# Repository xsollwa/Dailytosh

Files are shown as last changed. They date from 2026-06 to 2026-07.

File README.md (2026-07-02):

# DailyTosh
MacIntosh inspired **custom e-ink dashboard** featuring the hottest big-tech updates (+ the weather) and doubling as a business card holder!

[Click here for the demo video.](https://youtube.com/shorts/gpUzyWor4Is?si=RLWrw7KMKyLjlZAB)

**Photos:**




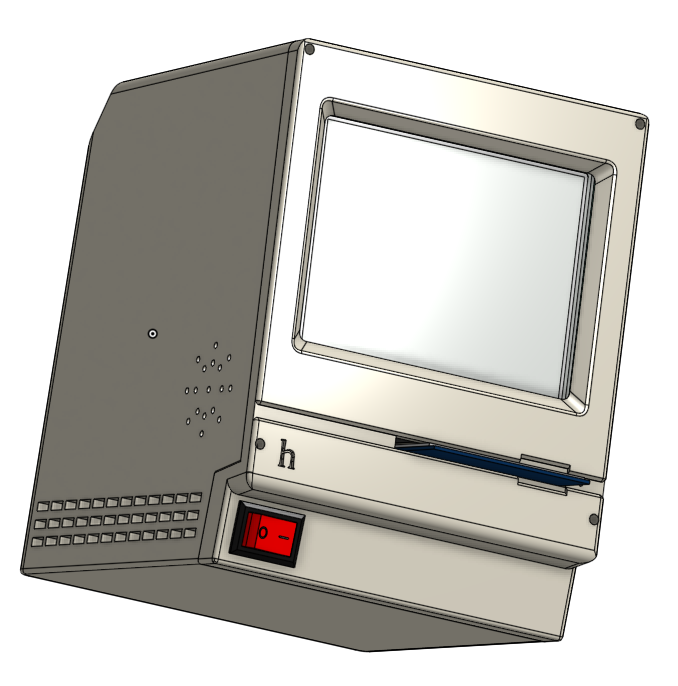
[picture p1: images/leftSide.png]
Side

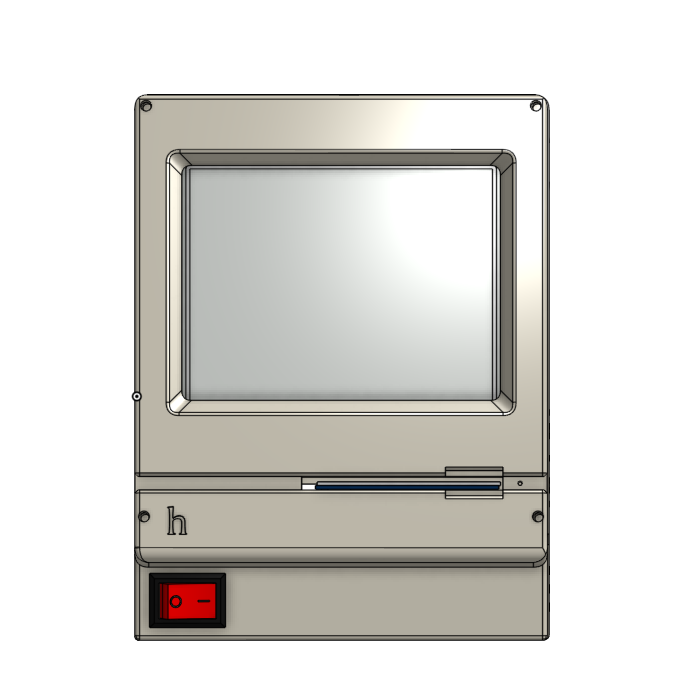
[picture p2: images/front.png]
Front

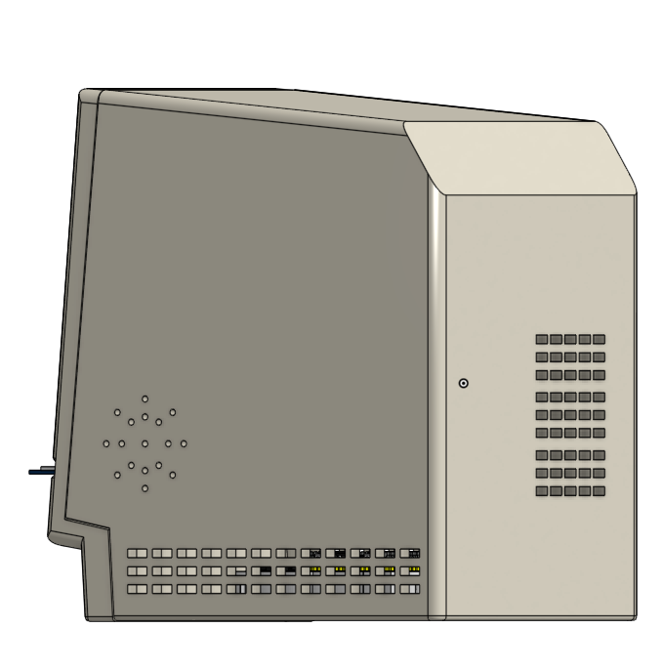
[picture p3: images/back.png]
Back

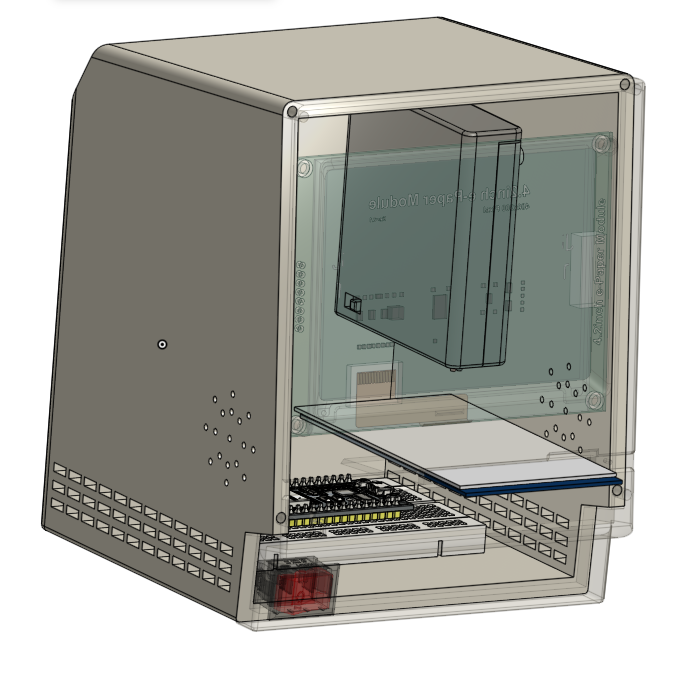
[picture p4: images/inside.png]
inside

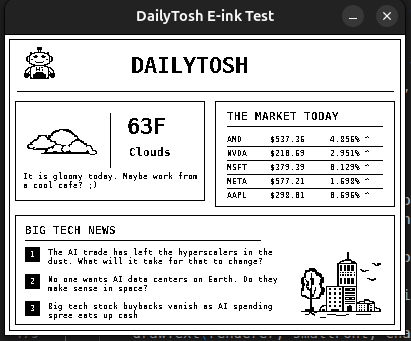
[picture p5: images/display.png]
display


## Why I made this project
Every morning, before heading out to school or work, I usually *check the weather, listen to WSJ Tech News Briefing and view market updates*. I realized a custon e-ink dashboard displaying all of this information would keep me informed more effotlessly! I was also interested in how E-Ink displays can fetch and display live information over Wi-Fi, and needed a better place to store my business cards.

*Built for Hack Club Outpost^^*

## Features
- Displays the most important big-tech news
- Shows major technology sector market changes
- Shares the weather of the day and suggests ideal workspace based on weather conditions 
    - Nice weather -> work outside
    - Rainy/snowy/windy weather -> work from home
    - Cloudy weather -> work at a coffee shop/library
- Uses an E-Ink display for less power consumption
- Doubles as a business card holder with its disk opening

## How It Works
DailyTosh is ESP32 based and uses a Waveshare E-Ink display

1. The ESP32 connects to Wi-Fi
2. It fetches data from OpenWeatherMap API (weather data) and Finnhub API (market and news data)
3. Data is processed and displayd with a dashboard layout
4. DailyTosh also includes a power switch!

### Wiring Diagram

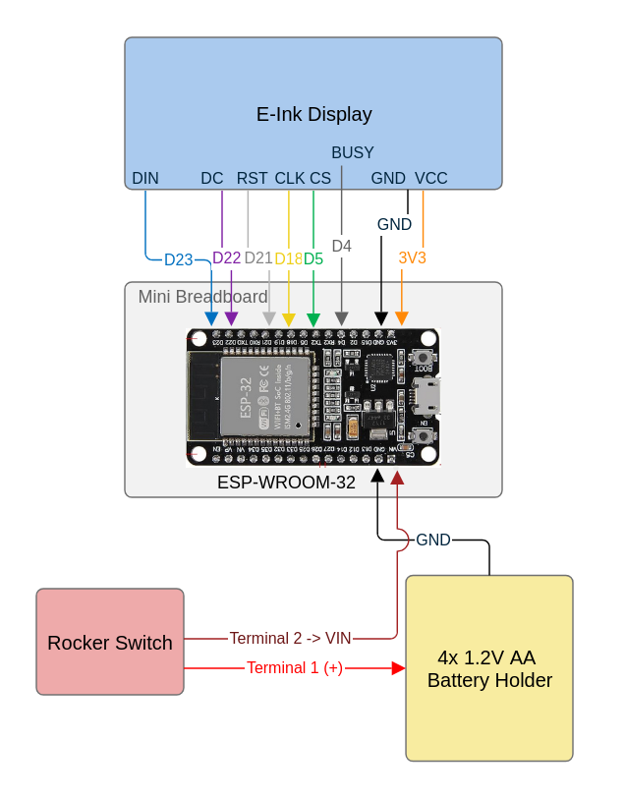
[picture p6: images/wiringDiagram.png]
Wiring Diagram


### Firmware

The ESP32 firmware *fetches weather, market and news data* from 2 APIs, processes the information and renders a custom dashboard on the E-Ink display.

**A custom filtering algorithm** scans over 100 big-tech keywords (for example " ai ", "amd", "semiconductor") to find the most relevant technology headlines on Finnhub. The firmware *refreshes every 24 hours* and was first developed as a **desktop C++ simulator** before being converted into ESP32 firmware in Arduino.

## Bill of Materials (BOM)

| Item | Purpose | Quantity | Cost | Link |
|---|---|---|---|---|
| Switch | Turning the power on/off | 1 | $0.00 (Owned) | [Link](https://a.co/d/0hRUtY8s) |
| M3 Bolts, Nuts, and Threaded Inserts | Mounting the components | 10 | $0.00 (Owned) | - |
| Cream PLA Filament | Printing the enclosure | 1 | $0.00 (Owned) | [Link](https://a.co/d/07ec5Kyy) |
| Micro USB Cable | Programming the ESP32 | 1 | $6.99 | [Link](https://a.co/d/0cJpSzp2) |
| Mini Breadboard and Jumper Wires | Connecting the circuit | 1 | $0.00 (Owned) | [Link](https://a.co/d/0ctxR1cS) |
| AA Batteries | Powering the circuit | 4 | $0.00 (Owned) | [Link](-) |
| 4 AA Battery Holder | Holding and connecting the batteries | 1 | $0.00 (Owned) | [Link](https://a.co/d/0bJuIjxS) |
| ESP-WROOM-32 | Processing and displaying information | 1 | $9.39 | [Link](https://a.co/d/0hTfNaHV) |
| 4.2" E-Ink Display (with matching cable) | Displaying information on the dashboard | 1 | $34.99 | [Link](https://www.waveshare.com/4.2inch-e-paper-module.htm) |

**Total Cost:** $51.37  
**Shipping:** $10.00  
**Taxes:** $1.84  

**Grand Total:** $63.21

## References
I used several resources for inspiration, learning and visualization purposes

### Tutorials
**ESP32 and Waveshare E-Ink Display Tutorial from YouTube:** Used to learn how to connect a Waveshare E-Ink display to an ESP32

https://youtu.be/El38zVmog14?si=65B1_IF447uCydue

### Design Inspiration
**The 20 Greatest Home Computers – The Guardian**: Reading through this article showed me a lot of cool famous computer designs

https://www.theguardian.com/games/2020/sep/07/the-20-greatest-home-computers-ranked

**Apple Macintosh (1984)**: The design and the name of DailyTosh is inspired by the original Macintosh computer

### CAD Models
These CAD models from GrabCAD were used in the Assembly for visualization purposes
- ESP-WROOM-32 model
- 4.2" Waveshare E-Ink Display
- Mini breadboard
- 4xAA Battery Holder

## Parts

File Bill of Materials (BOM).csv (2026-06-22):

Component | Purpose | Quantity | Total Price | Link | Distributor
Switch | Turning the power on/off | 1 | $0.00 | https://a.co/d/0hRUtY8s | N/A, I have it
M3 bolts, nuts and threaded inserts $0.00 - N/A, I have it | Mounting the components | 10 | $0.00 | N/A | N/A, I have it
Cream PLA | Printing the case | 1 | $0.00 | https://a.co/d/07ec5Kyy | N/A, I have it
Micro USB Cable | Programming the ESP32 | 1 | $6.99 | https://a.co/d/0cJpSzp2 | Amazon
Mini breadboard and jumping wires | Connecting the circuit | 1 | $0.00 | https://a.co/d/0ctxR1cS | N/A, I have it
AA batteries | Powering the circuit | 4 | $0.00 | N/A | N/A, I have it
4 AA Battery Holder | Holding the batteries | 1 | $0.00 | https://a.co/d/0bJuIjxS | N/A, I have it
ESP-WROOM-32 | Processing and displaying info | 1 | $9.39 | https://a.co/d/0hTfNaHV | Amazon
4.2inch E-Ink display w/ matching cable | Displaying information on the dashboard | 1 | $34.99 | https://www.waveshare.com/4.2inch-e-paper-module.htm | Waveshare
 | Tax: $1.84 | Shipping: $10.00
 | Total: $63.21

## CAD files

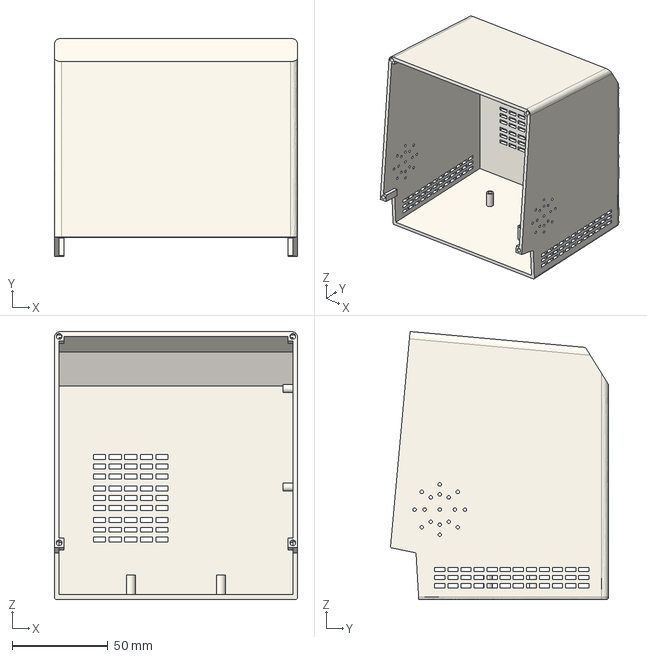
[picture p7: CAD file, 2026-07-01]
CAD/CaseFinal.step
127.0 x 113.9 x 139.9 mm

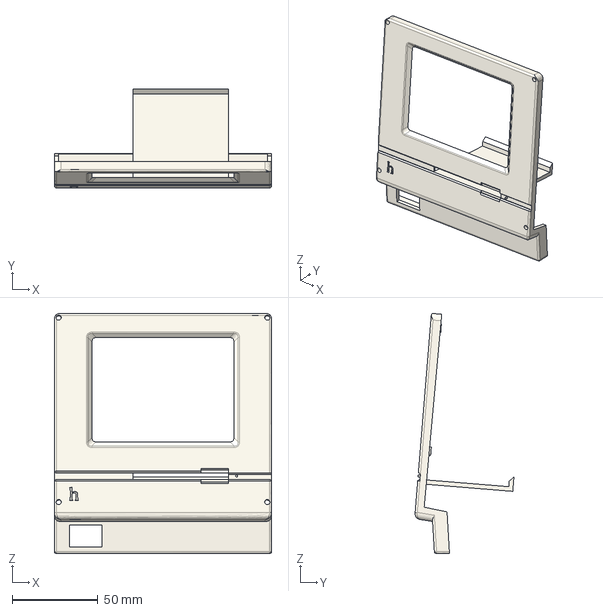
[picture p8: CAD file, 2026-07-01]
CAD/LidFinal.step
127.0 x 57.8 x 140.3 mm

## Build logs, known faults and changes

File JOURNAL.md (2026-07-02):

<!--
  This journal is auto generated by Stasis.
-->
# 7/1/2026 5 PM - Printing, sandpapering, assembling, demoing

_Time spent: 3.5h_

My printer printed the revised CAD model really badly, and after reprinting it a couple of more times, I decided to accept my fate and smooth out the case and the lid with sandpaper. After it looked smooth enough, I inserted the threaded inserts, redid some soldering, assembled my project, and recorded the demo! Unfortunately I forgot to document how horrible my print looked before sanding but here is a photo of my final project!



# 6/30/2026 6 PM - Fixing the CAD model

_Time spent: 1.5h_

To test out my 3D model, I printed out a prototype with the worst PLA I have on the fastest printing speed. As I tried placing my electrical components into the casing, I realized that my CAD had quite a few mistakes (e.g. cutouts that were too small, shell that was too thick and the whole model was pretty big for no reason). I also figured that I do not really need a breadboard. With that, I went back on OnShape, fixed all of those errors and sent the revised model to the printer. I also updated the repo with updated CAD models.




# 6/30/2026 1 AM - Building the Full Circuit

_Time spent: 1.5h_

After I got the software to work properly, I started assembling the full circuit by soldering the battery holder with the switch, and connecting them with the ESP32. At first, my ESP32 showed no signs of life. After checking the wiring and testing the batteries with a multimeter, I found no obvious connection issues. As a final test, I replaced the 3 rechargeable batteries with a fresh set of non-rechargeable ones. Fortunately, the circuit powered on!! The rechargeable batteries were most likely providing slightly less voltage than the ESP32 needed through the VIN pin :D

(I will have better wire management once my tape arrives....)



# 6/29/2026 9 PM - Testing Hardware and Fixing Software

_Time spent: 4h_

The hardware components of this project have finally arrived, and I proceeded with testing the ESP32 and then wired in the E-ink screen. After trying to run my firmware, it did not compile and I realized that it has a ton of bugs, since it was not tested before on an ESP32. I started by copy and pasting my old code and fixing it step by step in a new Arduino sketch. This made debugging less overwhelming. I spent lots of time adjusting the layout, re-converting my art to 0s and 1s and other such design things before utilizing the APIs. After I was satisfied with the layout, I plugged in the WiFi+API functionality and voila! The software works! 




# 6/22/2026 5 AM - All things Firmware and Finish

_Time spent: 0.75h_

To finish up the design for this project, I converted my bill of materials to a csv format and added it to the repository along with the firmware and additional assets. 

I also thought that I should journal my firmware development process here!

Since I did not have the ESP32 nor the E-Ink display yet, I first made a desktop c++ simulator that could fetch weather, market and news data from APIs and display everything in a "dashboard" view using a SDL2 simulation of a 400x300 pixel display. 

As I revised the layout, I added multiple stocks, pixel-art, weather based workspace recommendations and a custom filtering algorithm that scans 100+ tech related keywords to find relevant headlines. 

Once the simulator was working, I converted the code into esp32 compatible firmware by replacing the desktop networking, json and graphics libraries with the  stuff that can run on the microcontroller. 

Anyway, here is a screenshot of my simulated e-ink dashboard!

display

Also the first hour of my firmware  time was unfortunately not recorded in Hackatime because I initially wasn't working inside a project folder :__)



# 6/22/2026 2 AM - Pixel Art

_Time spent: 1.5h_

I used the Piskel platform to sketch out some pixel art for DailyTosh E-ink dashboard ui. I made a 32x32 mini robot, 64x64 clouds and a 64x64 city. This was my first time doing pixel art and I found it pretty fun.

 I also planned the overall dashboard layout for the display to neatly show the weather, market updates, and top 3 big tech headlines. 

New Piskel

New Piskel(1)

New Piskel(2)





# 6/20/2026 9 PM - README.md, Repo and Arduino IDE/Hackatime Setup

_Time spent: 2h_

I created and organized the GitHub repository for DailyTosh with all CAD files and project images. I also spent time writing and revising the README.md to include all of the required info and references. Since I recently started working on a new computer, I installed and configured Arduino IDE and connected Hackatime to track my firmware time down the line in this project.





# 6/20/2026 3 AM - Wiring Diagram and Tutorials

_Time spent: 2h_

First, I watched several YouTube tutorials and guides on how to connect a Waveshare E-Ink Display pins to an ESP32 board, since the Waveshare website did not explicitly say that my selected e-ink display can be used with ESP32 boards. 

After making sure that all of my components are compatible with each other, I made the wiring diagram for this project on SmartDraw. This diagram making platform was pretty painful to use (or maybe I just haven't figured out how to use it properly yet), so I hope to find a better one for my future projects.

Here is the wiring diagram:





# 6/20/2026 12 AM - Finished CAD Assembly

_Time spent: 1h_

Finished up the computer lid by adding mounting holes, the E-ink display and the switch. Assembled the final 3d model. 

I also made sample business cards to show how the business-card-holding slot is intended to look :)









Almost everything will be mounted using threaded inserts and screws, and the breadboard will be mounted using its sticky bottom or two-sided tape. I decided to use a breadboard instead of a pcb in this project because my circuit has only 4 components. I thought it would be more cost efficient than a pcb, especially because my soldering iron does not work :_)






# 6/19/2026 11 PM - CAD-ed the Case

_Time spent: 2h_

I designed the main old-computer looking case in OnShape. I also imported the electronic components that it holds (the batteries with the holder and the breadboard with ESP32) form GrabCAD and started my assembly.





I also revised my Bill of Materials to include threaded inserts for mounting and exclude the items that I already own (PLA and breadboard) to bring the material cost down.




# 6/19/2026 9 PM - CAD-ed the lid

_Time spent: 2h_

I designed the lid for the computer/display frame/electronics casing in OnShape. It is inspired by the Apple Macintosh computer. I also decided to make the opening for the disk drive into a business card holder to add another small feature (I have to many business cards laying on my desk)








# 6/19/2026 4 PM - Brainstorming and Design

_Time spent: 4h_

I want to make my own e-ink dashboard, so I started with brainstorming ideas on what it can display. I have been listening to Wall Street Journal tech minute everyday, so I ultimately decided to make an e-ink dashboard that would show big tech news, market changes and the weather.

I spent about an hour researching what APIs I can use for the information that I need. I will go with OpenWeatherMap API and Finnhub API, since they have free options and are "user friendly". 

I spent the next hour figuring out what my dashboard will look like. I wanted it to have a vintage look and be related to "big tech". I read this article called "The 20 greatest home computers ranked", and the 1984 Apple Macintosh became my design inspo. From there came the project name "Dailytosh"





For the last two hours, I searched for the most affordable options of the materials that I will need. An affordable e-ink display that is ESP32 compatible (for Wi-Fi purposes) was the hardest to find. I also made and entered my Bill of Materials on this website.




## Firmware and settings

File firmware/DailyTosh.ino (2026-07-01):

/*DailyTosh firmware!
 *This code connects the ESP32 to WiFi, 
 *fetches weather, stock and tech news, 
 *displays it on the e-ink screen, 
 *then puts the ESP32 into sleep until the next day
 *(translated to .ino syntax from the initial dailytosh-api-test.cpp code for ESP32 compatability)*/

#include <GxEPD2_BW.h>
#include <Fonts/FreeMonoBold12pt7b.h>
#include <Fonts/FreeMonoBold9pt7b.h>
#include <Fonts/FreeMono9pt7b.h>
#include <WiFi.h>
#include <HTTPClient.h>
#include <WiFiClientSecure.h>
#include <ArduinoJson.h>
#include <vector>
#define SECONDS_TO_SLEEP 86400 //1 day

//wifi info
const char* WIFI_SSID ="TMOBILE-B11A";
const char* WIFI_PASS = "v4strb6kf9c";


//API keys
String OPENWEATHERMAP_KEY = " "; 
String FINNHUB_KEY = " ";

String WEATHER_CITY = "Cleveland";
String WEATHER_COUNTRY = "US";

struct StockData{
  String symbol;
  float price = 0;
  float changePercent = 0;
};

struct NewsItem {
  String headline;
};


struct DailyToshData {
  int tempF = 63;
  String condition = "Clouds";
  String suggestion = "It is gloomy today. Maybe work from a cool cafe? ;)";

  std::vector<StockData> stocks;
  std::vector<NewsItem> headlines;
};

DailyToshData data;

//Waveshare e-ink display wiring
GxEPD2_BW<GxEPD2_420_GDEY042T81, GxEPD2_420_GDEY042T81::HEIGHT> display(
  GxEPD2_420_GDEY042T81(/*CS=*/5, /*DC=*/22, /*RST=*/21, /*BUSY=*/4)
);

const uint16_t BG = GxEPD_WHITE;
const uint16_t FG = GxEPD_BLACK;


const uint16_t BADGE_FILL = GxEPD_BLACK;
const uint16_t BADGE_TEXT = GxEPD_WHITE;

//my art converted to binary

const int CITY_W = 64;
const int CITY_H = 64;

const char* citySprite[] = {
  "0000000000000000000000000000000000000000000000000000000000000000",
  "0000000000000000000000000000000000000000000000000000000000000000",
  "0000000000000000000000000000000000000100000000000000000000000000",
  "0000000000000000000000000000000000000100000000000000000000000000",
  "0000000000000000000000000000000000000100000000000000000000000000",
  "0000000000000000000000000000000000000100000000000000000000000000",
  "0000000000000000000000000000000000000100000000000000000000000000",
  "0000000000000000000000000000000000000100000000000000000000000000",
  "0000000000000000000000000000000000011111000000000000000000000000",
  "0000000000000000000000000000000001111111100000000000000000000000",
  "0000000000000000000000000000000111000000111000000000000000000000",
  "0000000000000000000000000000001100000000111100000000000000000000",
  "0000000000000000000000000000011111111111111110000000000001100111",
  "0000000000000000000000000000010000000000000010000000000000110111",
  "0000000000000000000000000000010110110110110010000000000000011100",
  "0000000000000000000000000000010110110110110010000000000000000000",
  "0000000000000000000000000000010110110110110010000000000000000000",
  "0000001111100000000000000000010110110110110010000000000000000000",
  "0000001111110000000000000000010110110110110010011000000000000000",
  "0001111111111000000000000000010110110110110010001101110000000000",
  "0001111001111000000000000000010000000000000010000111000000000000",
  "0001100000011100000000000000010101010101101010000000000000000000",
  "0011000010011111000000000000010000000000000010000000000000000000",
  "0011000010001111100000000000010101010101101010000000000000000000",
  "0011000010000011100000000000010000000000000010000000000000000000",
  "0111000010000001110000000000010000000000000010000000000000000000",
  "1100000111000000110000000000010110110110110010000000011000110000",
  "1101000111000001110000000000010110110110110010000000001111110000",
  "1100100011000001110000000000010110110110110010000000000011000000",
  "1100110011000001110000000000010110110110110010000000000000000000",
  "1100010011000001110000000000010110110110110010000000000000000000",
  "1110010011000011100000000000010110110110110010000000000000000000",
  "0110110011000011100000000000010000000000000010000000000000000000",
  "0110110010000001100000000000010000000000000010000000000000000000",
  "0100100010000001100011111111111111111111111110000000000000000000",
  "0100110010010001110010000000000001000000000010000000000000000000",
  "1100010110010000111010110011001101011111111010000000000000000000",
  "1100011110010000111010110011001101011110011010000000000000000000",
  "1100001110110000111010000000000001011111111010000000000000000000",
  "1000000110100000111010000000000001000000000010000000000000000000",
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
};

const int CLOUD_W = 62;
const int CLOUD_H = 29;

const char* cloudSprite[] = {
  "00000000000000000000000000001111111110000000000000000000000000",
  "00000000000000000000000001111111111111100000000000000000000000",
  "00000000000000000000000111111111111111110000000000000000000000",
  "00000000000000000000001111111111111111111000000000000000000000",
  "00000000000000000000011111111111111111111100000000000000000000",
  "00000000000000000000011111111111111111111110000000000000000000",
  "00000000000011110000111111111111111111111111000000000000000000",
  "00000000001111111101111111111111111111111111000000000000000000",
  "00000000001100001101111111111111111111111111100000000000000000",
  "00000000011000000111111111111111111111111111100000000000000000",
  "00000000011000000011111111111111111111111111110000000000000000",
  "00000011110000000011111111111111111111111111111000000000000000",
  "00000111100000000000111111111111111111111111111110000000000000",
  "00001100000000000000111111111111111111111110000111100000000000",
  "00011000000000000000000011111111111111111000000011100000000000",
  "00010000000000000000000001111111111111110000000000111000000000",
  "01111000000000000000000001111111111111110000000000011000000000",
  "11100000000000000000000011001111111111100000000000001100000000",
  "11000000000000000000000110000011111011000000000000001111100000",
  "11000000000000000000011100000001100001000000000000001000110000",
  "11100110000000000001111100000001000000000000000000000000010000",
  "01111100111111111111001000000011000000000000000000000000011000",
  "00000111111111111110000000000010000000000000000000000000001000",
  "00000000000000001110000000000011000001000000000000000100001110",
  "00000000000000001100000111100001100111100000000000001110000011",
  "00000000000000011111111111111111111111111111111111111110000001",
  "00000000000011111111111111111111111111111111111111111111000011",
  "00000000000000000000000000000000000000000000000000000001100110",
  "00000000000000000000000000000000000000000000000000000000111100"
};

const int ROBOT_W = 32;
const int ROBOT_H = 32;

const char* robotSprite[] = {
  "00000000000000111110000000000000",
  "00000000000000111110000000000000",
  "00000000000000111110000000000000",
  "00000000000000010100000000000000",
  "00000000000000010100000000000000",
  "00000001100111111111110011000000",
  "00000001111100000000011111000000",
  "00000001100000000000000011000000",
  "00000011000011000001100001100000",
  "00001110001111100011111000111000",
  "00011010000111000001110000101100",
  "00011010000000000000000000101100",
  "00011010110000000000000110101100",
  "00011010000000000000000000101100",
  "00001110000010000000100000111000",
  "00000010000001111111000000100000",
  "00000011100000000000000011100000",
  "00000000111100000000011110000000",
  "00000000001111111111111000000000",
  "00000000111100000000011110000000",
  "00000111100001001011000011110000",
  "00001101000001001000000001011000",
  "00011001000001111001000001001100",
  "00110001000001001001000001000110",
  "00100011000000000000000001100010",
  "00100101000001111111000001010010",
  "01111101000011111111100001011111",
  "01111111001111111111111001111111",
  "01111111001111111111111001111111",
  "01111101001111111111111001011111",
  "00111001101111111111111011001110",
  "00000001111111111111111111000000"
};

//helpers I use to draw sprites, wrap text and format data

void drawSprite(const char* sprite[], int rows, int x, int y, int scale) {
  for (int row = 0; row < rows; row++) {
    for (int col = 0; sprite[row][col] != '\0'; col++) {
      if (sprite[row][col] == '1') {
        display.fillRect(x + col * scale, y + row * scale, scale, scale, FG);
      }
    }
  }
}

void drawSpriteResized(const char* sprite[], int srcW, int srcH, int x, int y, int targetW, int targetH) {
  for (int ty = 0; ty < targetH; ty++) {
    int sy = (long)ty * srcH / targetH;

    for (int tx = 0; tx < targetW; tx++) {
      int sx = (long)tx * srcW / targetW;

      if (sprite[sy][sx] == '1') {
        display.drawPixel(x + tx, y + ty, FG);
      }
    }
  }
}

void useTinyText() {
  display.setFont();
  display.setTextSize(1);
  display.setTextColor(FG);
}

void printWrapped(String text, int x, int y, int maxChars, int lineHeight, int maxLines) {
  int line = 0;

  while (text.length() > 0 && line < maxLines) {
    int cut = min(maxChars, (int)text.length());

    if (text.length() > maxChars) {
      int lastSpace = text.lastIndexOf(' ', maxChars);
      if (lastSpace > 0) cut = lastSpace;
    }

    display.setCursor(x, y + line * lineHeight);
    display.print(text.substring(0, cut));

    text = text.substring(cut);
    text.trim();
    line++;
  }
}

//suggestions: clear sky=work outside, cloudy=work at a cafe, rain/snow=work indoors
String chooseSuggestion(int tempF, String condition) {
  if (condition == "Rain" || condition == "Snow" || condition == "Thunderstorm") {
    return "It is a good idea to stay indoors and work from home today :)";
  } 
  else if (condition == "Clear") {
    return "Nice weather! Consider working from a park :D";
  } 
  else if (condition == "Clouds") {
    return "It is gloomy today. Maybe work from a cool cafe? ;)";
  } 
  else {
    return "Weather is unpredictable... cozy desk work session? :P";
  }
}

bool connectWiFi() {
  Serial.print("Connecting to WiFi");

  WiFi.mode(WIFI_STA);
  WiFi.begin(WIFI_SSID, WIFI_PASS);

  int tries = 0;

  while (WiFi.status() != WL_CONNECTED && tries < 30) {
    delay(500);
    Serial.print(".");
    tries++;
  }

  Serial.println();

  if (WiFi.status() == WL_CONNECTED) {
    Serial.println("WiFi connected.");
    Serial.print("IP address: ");
    Serial.println(WiFi.localIP());
    return true;
  }

  Serial.println("WiFi failed");
  return false;
}

String httpGet(String url) {
  HTTPClient http;
  WiFiClientSecure secureClient;

  Serial.println("Requesting:");
  Serial.println(url);

  if (url.startsWith("https://")) {
    secureClient.setInsecure();
    http.begin(secureClient, url);
  } else {
    http.begin(url);
  }

  int status = http.GET();

  Serial.print("HTTP status: ");
  Serial.println(status);

  if (status <= 0) {
    Serial.print("HTTP error: ");
    Serial.println(http.errorToString(status));
    http.end();
    return "";
  }

  String response = http.getString();
  http.end();

  return response;
}

String formatPrice(float price) {
  return "$" + String(price, 2);
}

String formatChange(float changePercent) {
  String text = "";

  if (changePercent >= 0) {
    text += "+";
  }

  text += String(changePercent, 2);
  text += "%";

  return text;
}

void fetchMarket(String symbol, DailyToshData &data) {

  String url = "https://finnhub.io/api/v1/quote?symbol=";
  url += symbol;
  url += "&token=";
  url += FINNHUB_KEY;

  String response = httpGet(url);

  if (response == "") {
    Serial.println("Empty");
    return;
  }

  StaticJsonDocument<1024> doc;
  DeserializationError error = deserializeJson(doc, response);

  if (error) {
    Serial.print("Stock JSON parse failed for ");
    Serial.print(symbol);
    Serial.print(": ");
    Serial.println(error.c_str());
    return;
  }

  if (doc.containsKey("error")) {
    Serial.print("Finnhub stock error for ");
    Serial.print(symbol);
    Serial.print(": ");
    Serial.println(doc["error"].as<String>());
    return;
  }

  float currentPrice = doc["c"] | 0.0;
  float percentChange = doc["dp"] | 0.0;

  StockData stock;
  stock.symbol = symbol;
  stock.price = currentPrice;
  stock.changePercent = percentChange;

  data.stocks.push_back(stock);

  Serial.print("Stock parsed: ");
  Serial.print(stock.symbol);
  Serial.print(" ");
  Serial.print(stock.price);
  Serial.print(" ");
  Serial.print(stock.changePercent);
  Serial.println("%");
}

String toLowerCase(String text) {
  text.toLowerCase();
  return text;
}

//a bunch of key words to filter through the headlines and get only big tech news
bool isBigTechHeadline(String headline) {
  String h = toLowerCase(headline);

   String keywords[] = {
    "openai",
    "chatgpt",
    "gpt",
    "gpt-4",
    "gpt-5",
    "sam altman",
    "sora",
    "operator",
    "codex",
    "anthropic",
    "claude",
    "dario amodei",
    "constitutional ai",
    "nvidia",
    "nvda",
    "jensen huang",
    "cuda",
    "blackwell",
    "hopper",
    "h100",
    "h200",
    "b100",
    "b200",
    "dgx",
    "grace blackwell",
    "amd",
    "ryzen",
    "epyc",
    "radeon",
    "instinct",
    "mi300",
    "mi325",
    "mi350",
    "lisa su",
    "microsoft",
    "msft",
    "azure",
    "copilot",
    "github copilot",
    "satya nadella",
    "meta",
    "facebook",
    "instagram",
    "threads",
    "whatsapp",
    "llama",
    "mark zuckerberg",
    "zuckerberg",
    "google",
    "alphabet",
    "googl",
    "gemini",
    "deepmind",
    "sundar pichai",
    "veo",
    "imagen",
    "apple",
    "aapl",
    "apple intelligence",
    "tim cook",
    "siri",
    "amazon",
    "aws",
    "bedrock",
    "andy jassy",
    "amazon web services",
    "tesla",
    "optimus",
    "xai",
    "grok",
    "elon musk",
    "robotics",
    "robot",
    "humanoid",
    "figure ai",
    "figure",
    "agility robotics",
    "boston dynamics",
    "unitree",
    "sanctuary ai",
    "mistral",
    "cohere",
    "perplexity",
    "midjourney",
    "stability ai",
    "runway",
    "hugging face",
    "semiconductor",
    "chip",
    "chips",
    "chipmaker",
    "chipmakers",
    "gpu",
    "gpus",
    "cpu",
    "cpus",
    "accelerator",
    "ai accelerator",
    "artificial intelligence",
    " ai ",
    "genai",
    "machine learning",
    "deep learning",
    "large language model",
    "llm",
    "foundation model",
    "agentic ai",
    "reasoning model",
    "multimodal",
    "datacenter",
    "data center",
    "cloud computing",
    "cloud",
    "open source ai",
    "venture capital",
    "startup",
    "silicon valley",
    "y combinator",
    "yc",
    "tech giant",
    "big tech"
  };

  int keywordCount = sizeof(keywords) / sizeof(keywords[0]);

  for (int i = 0; i < keywordCount; i++) {
    if (h.indexOf(keywords[i]) != -1) {
      return true;
    }
  }

  return false;
}

void fetchNews(DailyToshData &data) {

  String url = "https://finnhub.io/api/v1/news?category=technology&token=";
  url += FINNHUB_KEY;

  String response = httpGet(url);

  if (response == "") {
    Serial.println("Empty news");
    return;
  }

  DynamicJsonDocument doc(32768);
  DeserializationError error = deserializeJson(doc, response);

  if (error) {
    Serial.print("News JSON parse failed: ");
    Serial.println(error.c_str());
    return;
  }

  if (!doc.is<JsonArray>()) {
    Serial.println("News response was not an array");
    return;
  }

  for (int i = 0; i < doc.size() && data.headlines.size() < 3; i++) {
    String headline = doc[i]["headline"] | "";

    if (headline == "") {
      continue;
    }

    if (isBigTechHeadline(headline)) {
      NewsItem item;
      item.headline = headline;
      data.headlines.push_back(item);

      Serial.print("News headline added: ");
      Serial.println(headline);
    }
  }

  if (data.headlines.size() == 0) {
    NewsItem item;
    item.headline = "No big tech news today!";
    data.headlines.push_back(item);
  }
}

void fetchWeather(DailyToshData &data) {

  String url = "http://api.openweathermap.org/data/2.5/weather?q=";
  url += WEATHER_CITY;
  url += ",";
  url += WEATHER_COUNTRY;
  url += "&units=imperial&appid=";
  url += OPENWEATHERMAP_KEY;

  Serial.println("Requesting weather:");
  Serial.println(url);

  HTTPClient http;
  http.begin(url);

  int httpCode = http.GET();

  Serial.print("HTTP status: ");
  Serial.println(httpCode);

  if (httpCode != 200) {
    Serial.println("Weather failed");
    http.end();
    return;
  }

  String payload = http.getString();
  http.end();

  StaticJsonDocument<2048> doc;
  DeserializationError error = deserializeJson(doc, payload);

  if (error) {
    Serial.print("JSON parse failed: ");
    Serial.println(error.c_str());
    return;
  }

  float temp = doc["main"]["temp"] | 63.0;
  const char* conditionText = doc["weather"][0]["main"] | "Clouds";

  data.tempF = (int)round(temp);
  data.condition = String(conditionText);
  data.suggestion = chooseSuggestion(data.tempF, data.condition);

  Serial.println("Weather parsed:");
  Serial.print("Temp F: ");
  Serial.println(data.tempF);
  Serial.print("Condition: ");
  Serial.println(data.condition);
  Serial.print("Suggestion: ");
  Serial.println(data.suggestion);
}


void drawTrendIcon(float changePercent, int x, int y) {
  if (changePercent >= 0) {
    display.fillTriangle(x + 4, y, x, y + 7, x + 8, y + 7, FG);
  } else {
    display.fillTriangle(x, y, x + 8, y, x + 4, y + 7, FG);
  }
}

void drawMarketRow(String symbol, String price, String change, float changePercent, int y) {
  useTinyText();

  display.setCursor(224, y);
  display.print(symbol);

  display.setCursor(270, y);
  display.print(price);

  display.setCursor(328, y);
  display.print(change);

  drawTrendIcon(changePercent, 370, y - 1);
}

void drawNewsItem(int number, const String& headline, int y) {
  useTinyText();

  display.fillRect(24, y - 8, 13, 13, BADGE_FILL);

  display.setTextColor(BADGE_TEXT);
  display.setCursor(28, y - 6);
  display.print(number);

  display.setTextColor(FG);
  printWrapped(headline, 46, y - 8, 40, 9, 2);
}

// draws the final dashboard layout

void drawDashboard() {
  display.fillScreen(BG);
  display.setTextColor(FG);

  display.drawRect(6, 6, 388, 288, FG);

  // header
  drawSprite(robotSprite, ROBOT_H, 22, 8, 1);

  display.setFont();
  display.setTextSize(3);
  display.setTextColor(FG);
  display.setCursor(118, 17);
  display.print("DAILYTOSH");
  display.setTextSize(1);

  display.drawLine(14, 44, 386, 44, FG);

  display.drawRect(14, 48, 194, 114, FG);   // weather
  display.drawRect(216, 48, 170, 114, FG);  // market

  display.drawRect(14, 166, 372, 122, FG);  

  // weather section
  drawSpriteResized(cloudSprite, CLOUD_W, CLOUD_H, 22, 68, 88, 42);

  display.drawLine(120, 66, 120, 124, FG);

  display.setFont(&FreeMonoBold12pt7b);
  display.setTextColor(FG);
  display.setCursor(134, 83);
  display.print(data.tempF);
  display.print("F");

  display.setFont(&FreeMonoBold9pt7b);
  display.setCursor(130, 111);
  display.print(data.condition);

  useTinyText();
  printWrapped(data.suggestion, 24, 136, 27, 9, 2);

  display.setFont(&FreeMono9pt7b);
  display.setTextColor(FG);
  display.setCursor(226, 68);
  display.print("MARKET");
  display.drawLine(226, 78, 374, 78, FG);

  if (data.stocks.size() > 0) {
    int marketY = 92;

    for (int i = 0; i < data.stocks.size() && i < 4; i++) {
      StockData stock = data.stocks[i];

      drawMarketRow(
        stock.symbol,
        formatPrice(stock.price),
        formatChange(stock.changePercent),
        stock.changePercent,
        marketY
      );

      marketY += 17;
    }
  } else {
    drawMarketRow("AMD",  "$137.36", "+4.85%", 4.85, 92);
    drawMarketRow("NVDA", "$218.59", "+2.95%", 2.95, 109);
    drawMarketRow("MSFT", "$379.39", "+0.12%", 0.12, 126);
    drawMarketRow("AAPL", "$295.81", "+0.69%", 0.69, 143);
  }

  display.setFont(&FreeMono9pt7b);
  display.setTextColor(FG);
  display.setCursor(24, 186);
  display.print("BIG TECH NEWS");
  display.drawLine(24, 194, 290, 194, FG);

  if (data.headlines.size() > 0) {
    int newsY = 210;

    for (int i = 0; i < data.headlines.size() && i < 3; i++) {
      drawNewsItem(i + 1, data.headlines[i].headline, newsY);
      newsY += 29;
    }
  } else {
    drawNewsItem(1, "AI trade leaves hyperscalers behind.", 210);
    drawNewsItem(2, "Could data centers work in space?", 239);
    drawNewsItem(3, "AI spending eats into buybacks.", 266);
  }

  drawSpriteResized(citySprite, CITY_W, CITY_H, 292, 199, 88, 88);
}

///////

void setup() {
  Serial.begin(115200);
  delay(2000);

  bool wifiOK = connectWiFi();

  if (wifiOK) {
    fetchWeather(data);

    data.stocks.clear();
    fetchMarket("AMD", data);
    fetchMarket("NVDA", data);
    fetchMarket("MSFT", data);
    fetchMarket("AAPL", data);

    data.headlines.clear();
    fetchNews(data);
  }

  display.init(115200, true, 2, false);
  display.setRotation(0);
  display.setFullWindow();

  display.firstPage();
  do {
    drawDashboard();
  } while (display.nextPage());

  display.hibernate();
  Serial.println("ESP32 going to sleep");
  delay(1000);

  esp_sleep_enable_timer_wakeup((uint64_t)SECONDS_TO_SLEEP * 1000000ULL);
  esp_deep_sleep_start();
}

void loop() {
}

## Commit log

2026-06-20 added CAD files
    [case.step, lid.step]
2026-06-22 added bom
    [Bill of Materials (BOM).csv]
2026-06-30 Update JOURNAL.md with recent project progress
    Added journal entries detailing circuit assembly and software testing.
2026-07-01 Update journal with CAD model fixes
    Documented issues and fixes for the CAD model after prototype testing.
2026-07-02 Document printing and assembly process in JOURNAL.md
